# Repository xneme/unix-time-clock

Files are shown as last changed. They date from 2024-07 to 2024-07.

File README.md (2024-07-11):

# Binary Unix time clock

Worried about the impending Y2K38 problem? Want to see how much breathing room we still have at a single glance? This is the clock for you.
Inspired by numerical Unix time clocks, but slightly less (or more) useful.

## Hardware
This project uses an ESP32 board and a 32 pixel long WS2812 addressable led strip or ring.
Tested on:
 - [32 Bit WS2812 ring](https://www.aliexpress.com/item/1005006358767684.html)
 - [Lolin D32 Pro](https://www.aliexpress.com/item/32883116057.html) Rust firmware works fine.
 - [Lolin S3 Mini](https://www.aliexpress.com/item/1005005449219195.html) Dual core, but keeps glitching with Rust firmware. 
 - [ESP32-C3 Super Mini](https://www.aliexpress.com/item/1005006334515931.html) Single core, C firmware works fine.

 Board with dual core cpu is preferred, making it possible to run LED control and WiFi on separate cores so that WiFi interrupts do not mess up the timings of WS2812.
 Rust version of the software uses two cores and uses built in SNTP features of ESP32 to keep internal clock accurate.
 PlatformIO (C / Arduino) version uses a single core and drops the WiFi connection after synchronizing with NTP server and relies purely on the internal clock accuracy. Internal clock might drift significantly so the board needs to be reset every now and then to keep the clock somewhat accurate.

## Installation
Rust version uses ESP-RS std approach. [Instructions to set up dev environment](https://docs.esp-rs.org/book/installation/index.html).
After installation you can compile, upload and monitor with command `cargo run`.

C version uses [PlatformIO](https://platformio.org/).
After installation you can compile, upload and monitor with `pio run -e esp-c3-supermini -t upload -t monitor`.

You need to modify `src/main.rs` or `src/main.cpp` to add your own WiFi credentials and check the specified pin for controlling the LEDs matches the pin you are planning to use.

## Level shifting
ESP32 runs on 3.3V, while according to specs WS2812 requires signal of 0.7*VCC, so 3,5V for 5V LEDs. This works fine most of the time, but in case you have bad luck, you need to level shift the control line to 5V.
More info about this at [adafruit website](https://learn.adafruit.com/neopixel-levelshifter/shifting-levels).

## Enclosure
Clock body is printed in PLA with 0.4mm nozzle and 0.2mm layer height. Keyhole slots have one layer of support bridging under them, clean up the slots if you intend to use them. There is currently only a mount for D32 Pro board, which covers most of the pads. I split it in two in slicer and printed the part with groove standing up with small supports under the screw mounts. Mount is attached with four 2x10mm plastic screws. Ring is being held down with the board mount and few pieces of Kapton tape.

## TODO:
- Get a smaller 2 core board to work, D32 is a total overkill.

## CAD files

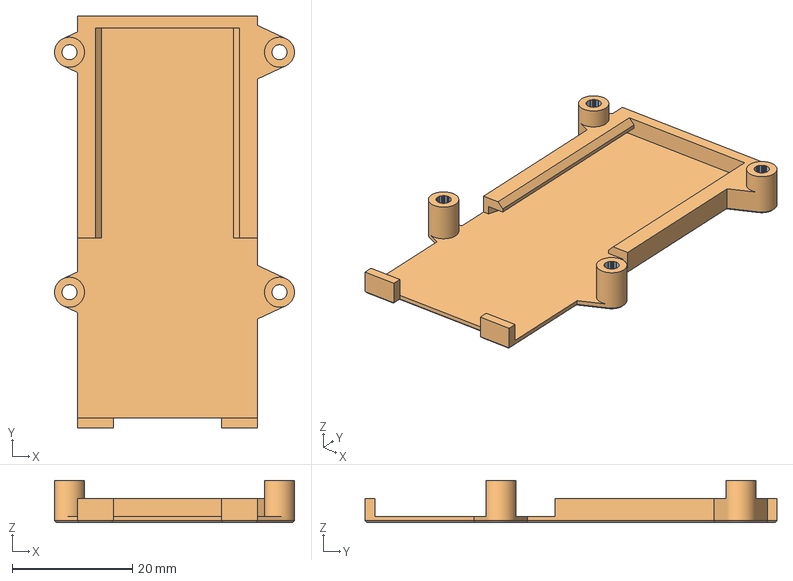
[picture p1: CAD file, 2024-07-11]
enclosure/d32_pro_board_adapter.FCStd
40.0 x 68.6 x 7.00 mm
board_adapter
board_adapter (Meshed)

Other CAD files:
enclosure/d32_pro_board_adapter.stl

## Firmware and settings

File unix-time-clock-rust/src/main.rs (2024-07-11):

use chrono::{DateTime, Utc};
use esp_idf_hal::cpu::Core;
use esp_idf_hal::delay::FreeRtos;
use esp_idf_hal::peripherals::Peripherals;
use esp_idf_hal::task::thread::ThreadSpawnConfiguration;
use esp_idf_svc::sntp::{EspSntp, SyncStatus};
use smart_leds::SmartLedsWrite;
use std::time::SystemTime;
use ws2812_esp32_rmt_driver::driver::color::LedPixelColorGrb24;
use ws2812_esp32_rmt_driver::{LedPixelEsp32Rmt, RGB8};

const SSID: &'static str = "SSID"; // Your SSID
const PASS: &'static str = "PASSWORD"; // Your Wifi Password

mod wifi;

fn main() -> ! {
    // It is necessary to call this function once. Otherwise some patches to the runtime
    // implemented by esp-idf-sys might not link properly. See https://github.com/esp-rs/esp-idf-template/issues/71
    esp_idf_sys::link_patches();

    let peripherals = Peripherals::take().unwrap();
    let modem = peripherals.modem;
    let led_pin = peripherals.pins.gpio15;
    let channel = peripherals.rmt.channel0;

    let _w = wifi::configure(SSID, PASS, modem).expect("Could not configure wifi");

    let ntp = EspSntp::new_default().unwrap();

    // Synchronize NTP
    println!("Synchronizing with NTP server");
    while ntp.get_sync_status() != SyncStatus::Completed {}
    println!("Time sync completed");

    println!("Starting LEDs");

    // Led control task has to be pinned to core 1 to avoid timing issues caused by wifi
    // interrupts on core 0
    ThreadSpawnConfiguration {
        pin_to_core: Some(Core::Core1),
        priority: 24,
        ..Default::default()
    }
    .set()
    .expect("Could not set thread spawn config");

    std::thread::spawn(move || {
        let mut led_strip =
            LedPixelEsp32Rmt::<RGB8, LedPixelColorGrb24>::new(channel, led_pin).unwrap();
        let pixels = std::iter::repeat(RGB8::from((0, 0, 0))).take(32);
        led_strip.write(pixels).unwrap();

        // Obtain System Time, convert to UTC Time, and get Unix Timestamp
        let st_now = SystemTime::now();
        let dt_now_utc: DateTime<Utc> = st_now.clone().into();
        let unix_timestamp = dt_now_utc.timestamp() + 2;

        let unix_timestamp_bits = format!("{unix_timestamp:032b}");

        let pixels = bitstring_to_pixels(&unix_timestamp_bits);
        startup_animation(&mut led_strip, pixels);
        loop {
            let st_now = SystemTime::now();
            let dt_now_utc: DateTime<Utc> = st_now.clone().into();
            let unix_timestamp = dt_now_utc.timestamp();

            let unix_timestamp_bits = format!("{unix_timestamp:032b}");

            let pixels = bitstring_to_pixels(&unix_timestamp_bits);
            led_strip.write(pixels).unwrap();

            // Print Time
            println!("{} = {}", unix_timestamp_bits, unix_timestamp);
            // Delay
            FreeRtos::delay_ms(1000);
        }
    });

    loop {
        FreeRtos::delay_ms(1000);
    }
}

fn bitstring_to_pixels(bitstring: &str) -> Vec<RGB8> {
    let mut pixels = Vec::new();
    for c in bitstring.chars().rev() {
        match c {
            '0' => pixels.push(RGB8::from((0, 0, 0))),
            '1' => pixels.push(RGB8::from((20, 0, 0))),
            _ => (),
        }
    }
    pixels
}

// Draws green mask over the clock face and then reveals the pixels representing the time
fn startup_animation(
    led_strip: &mut LedPixelEsp32Rmt<RGB8, LedPixelColorGrb24>,
    time_pixels: Vec<RGB8>,
) {
    let mask = std::iter::repeat(RGB8::from((0, 5, 0)))
        .take(32)
        .collect::<Vec<RGB8>>();

    let mut pixels = std::iter::repeat(RGB8::from((0, 0, 0)))
        .take(32)
        .collect::<Vec<RGB8>>();

    for index in 0..32 {
        pixels[index] = mask[index];
        led_strip.write(pixels.clone()).unwrap();
        FreeRtos::delay_ms(25);
    }
    FreeRtos::delay_ms(200);
    for index in (0..32).rev() {
        pixels[index] = time_pixels[index];
        led_strip.write(pixels.clone()).unwrap();
        FreeRtos::delay_ms(25);
    }
}

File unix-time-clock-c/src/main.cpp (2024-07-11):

#include "time.h"
#include <WiFi.h>
#include <rmt_led_strip.hpp>

// 32 LEDs, pin 15
arduino::ws2812 leds(15, 32);

const char *ssid = "SSID";         // Your wifi ssid
const char *password = "PASSWORD"; // Your wifi password

const char *ntpServer = "pool.ntp.org";
const long gmtOffset_sec = 0;
const int daylightOffset_sec = 3600;
time_t now;
struct tm timeinfo;

void printLocalTime() {
  struct tm timeinfo;
  if (!getLocalTime(&timeinfo)) {
    Serial.println("Failed to obtain time");
    return;
  }
  Serial.println(&timeinfo, "%A, %B %d %Y %H:%M:%S");
}

void full_green() {
  for (int i = 0; i < 32; i++) {
    leds.color(i, 0, 10, 0);
  }
  leds.update();
}

void full_blue() {
  for (int i = 0; i < 32; i++) {
    leds.color(i, 0, 0, 10);
  }
  leds.update();
}

void revealTime(time_t time) {
  full_green();
  delay(1000);

  time = time + 2; // Reveal takes 2 seconds

  for (int reveal_index = 32; reveal_index >= 0; reveal_index--) {
    uint32_t bitmask = 0b10000000000000000000000000000000;
    for (int led_index = 31; led_index >= reveal_index; led_index--) {
      if (bitmask & time) {
        leds.color(led_index, 30, 0, 0);
      } else {
        leds.color(led_index, 0, 0, 0);
      }
      bitmask >>= 1;
    }
    leds.update();
    delay(30);
  }
  delay(10); // Wait for to make reveal take exactly 2 seconds
}

void setup() {

  Serial.begin(115200);

  Serial.printf("Starting...");
  leds.initialize();
  full_blue();
  // connect to WiFi
  Serial.printf("Connecting to %s ", ssid);
  WiFi.begin(ssid, password);
  while (WiFi.status() != WL_CONNECTED) {
    delay(500);
    Serial.print(".");
  }
  Serial.println(" CONNECTED");

  // init and get the time
  configTime(gmtOffset_sec, daylightOffset_sec, ntpServer);
  getLocalTime(&timeinfo);

  // disconnect WiFi as it's no longer needed
  WiFi.disconnect(true);
  WiFi.mode(WIFI_OFF);
  time(&now);
  revealTime(now);
}

void loop() {
  time(&now);
  Serial.println(now, BIN);
  int led_index = 31;
  uint32_t bitmask = 0b10000000000000000000000000000000;
  for (; bitmask > 0; bitmask >>= 1) {
    if (bitmask & now) {
      leds.color(led_index, 30, 0, 0);
    } else {
      leds.color(led_index, 0, 0, 0);
    }
    led_index--;
  }
  leds.update();
  delay(1000);
}

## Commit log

2024-07-03 Squashed incomplete versions into one commit
    Moved LED control to Core1, moved wifi to module
    LEDs were occasionally glitching due to WiFi interrupts on same core.
    Moved LED control task to the other core. Issue of the problem: https://github.com/cat-in-136/ws2812-esp32-rmt-driver/issues/33
    [main.rs]
2024-07-11 Add enclosure files, switch default pin to 15
    [board_adapter.FCStd, board_adapter.stl]
2024-07-11 Fix board mount naming
    [d32_pro_board_adapter.FCStd, d32_pro_board_adapter.stl]
